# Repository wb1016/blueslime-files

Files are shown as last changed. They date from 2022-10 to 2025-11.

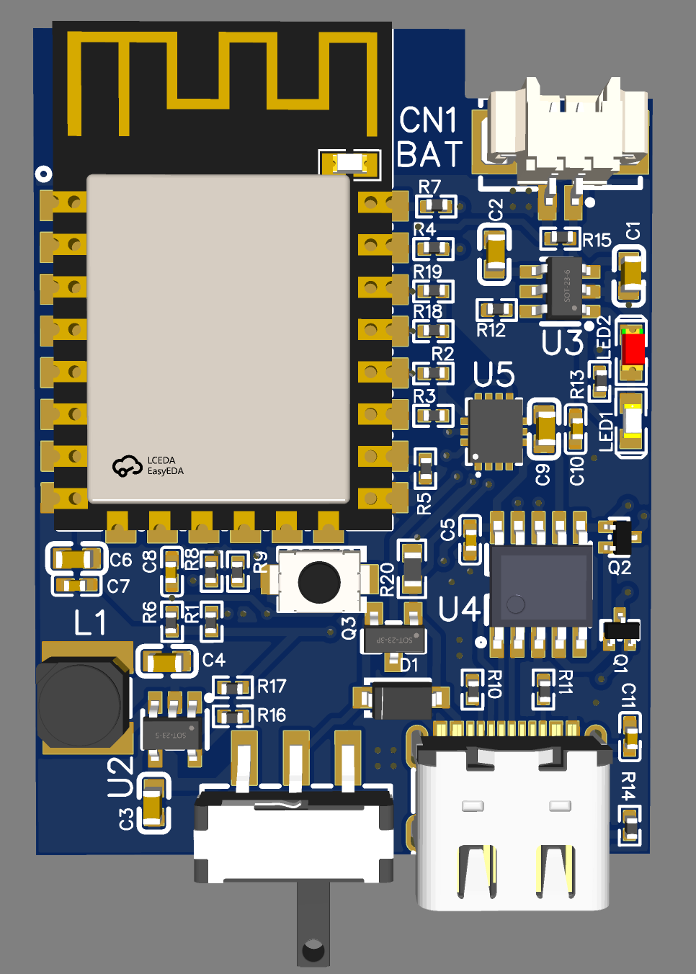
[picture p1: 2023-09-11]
r5-0904/3dpreview.png

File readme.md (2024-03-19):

# DISCONTINUED
see [BlueSlime-C3](https://github.com/wb1016/BlueSlime-C3) instead
# BlueSlime SlimeVR PCB Assembly
SlimeVR tracker hardware based on Wemos D1 Mini. comes with various revision.
### what revision should i select?
| revision | IMU | test | case | AUX |
|---|-----|---|---|-----|
| R1 | BMI160 | fail | y | y |
| R2 | BMI160 | untested | y | y | 
| R3 | BMI160 | untested | n | y |
| R3 (modular) | BMI160 | untested | n | y |
| R4 | BMI160 | untested | y | y |
| R4 (42688) | ICM-42688-P | untested | y | y |
| R5 | BMI270 | tested | y | n |

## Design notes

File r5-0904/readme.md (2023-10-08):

# revision 5 - 2023 09 04
first implementation of buck convertor and BMI270. better tracking performance and better power efficiency. extension is omitted.
## specs
- BMI270 IMU
- TP4057 500mA
- battery charge switch MOSFET
- reset button
- 51021 RB type battery connector
- optional JST-PH battery connector
- no THT components 
- 3x4cm form-factor
- flat bottom surface
## firmware configuration
- Board: WeMos D1 Mini
- Primary IMU: BMI270
- IMU Rotation: 0
- battery detection 180k ohm (default)
## battery requirements
DTP103040 will work flawlessly
- 51021 connector or JST-PH 2 pin connector
- integrated over-discharge protection circuit
- 10x30x40mm size

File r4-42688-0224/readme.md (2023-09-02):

# rev 4 (ICM-42688) - 2023 02 24
same with revision 4 but comes with ICM-42688-P IMU. maybe this is the most dense SlimeVR tracker i think. external oscilator clock enabled.

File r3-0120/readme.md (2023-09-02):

# revision 3 - 2023 01 20
similar with R2, but omitted some components and used experimental form factor.
## specs
- BMI160 IMU
- TC4056A 500mA
- FS312F-G battery protection IC
- battery protection MOSFET
- 51021 RB type battery connector
- optional JST-PH battery connector
- JST-PH extension connector
## firmware configuration
- Board: WeMos D1 Mini
- Primary IMU: BMI160
- IMU Rotation: 90 or 270
- battery detection 180k ohm (default)

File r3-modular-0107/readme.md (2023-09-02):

# revision 3 (modular version) - 2023 01 07
same with R3 but uses IMU module instead of doing SMT.

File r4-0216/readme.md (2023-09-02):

# revision 4 - 2023 02 16
huge revolution in form-factor. it comes with small size of 3x4cm. battery protection circuit is omitted since protected battery comes with them.
## specs
- BMI160 IMU
- TP4057 500mA
- battery charge switch MOSFET
- reset button
- 51021 RB type battery connector
- optional JST-PH battery connector
- JST-GH extension connector
- no THT components 
- 3x4cm form-factor
- flat bottom surface
## firmware configuration
- Board: WeMos D1 Mini
- Primary IMU: BMI160
- IMU Rotation: 90 or 270
- battery detection 180k ohm (default)
## battery requirements
DTP103040 will work flawlessly
- 51021 connector or JST-PH 2 pin connector
- integrated over-discharge protection circuit
- 10x30x40mm or 8x40x40 size

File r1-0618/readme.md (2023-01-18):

# revision 1 - 2022 06 18 
this is experimental early prototype. though this revision can operate without major issue, it designed under bad engineering practice. im not releasing PCB schematic.

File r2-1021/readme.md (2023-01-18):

# revision 2 - 2022 10 21
it is first revision that does not require additional fixes. and it is DIY-ready. you can order the assembled PCB with minimal modification.
## specs
- TP4056 500mA
- FS312F-G battery protection IC
- battery protection MOSFET
- reset button
- 51021 RB type battery connector
- optional JST-PH battery connector
- JST-GH extension connector
- no THT components

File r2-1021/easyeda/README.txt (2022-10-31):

<p>asdf</p>            
How to use：

At editor, open the document via: Top menu - File - Open - EasyEDA... , and select the json file, then open it at the editor, you can save it into a project.

如何使用：

打开编辑器，通过：顶部菜单 - 文件 - 打开 - 立创EDA... ，选择 json 文件打开在编辑器，你可以保存文档进工程里面。

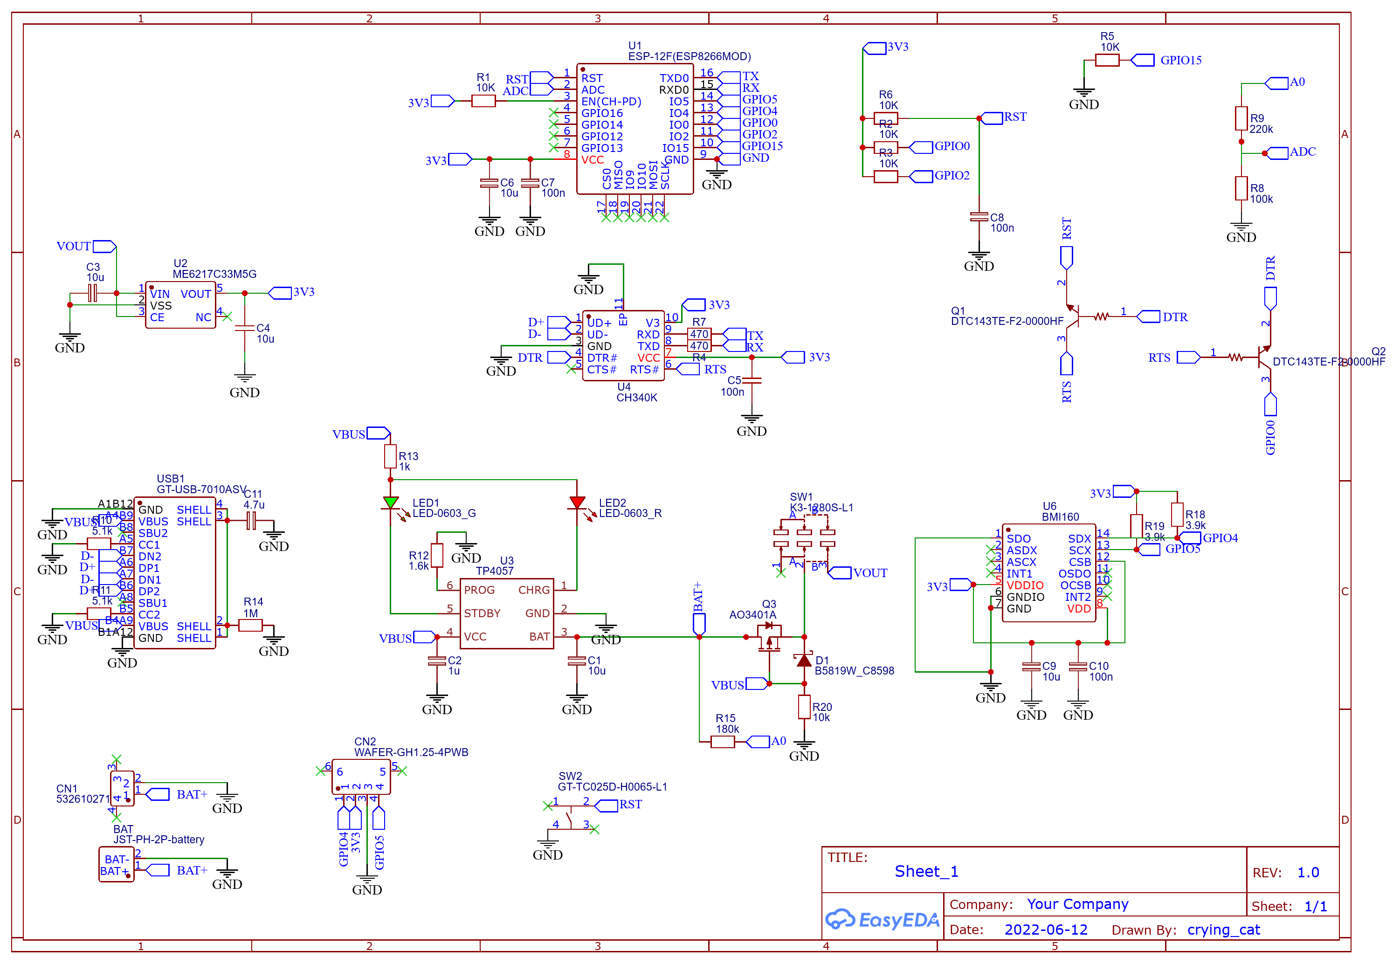
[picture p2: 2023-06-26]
r4-0216/Schematic.png

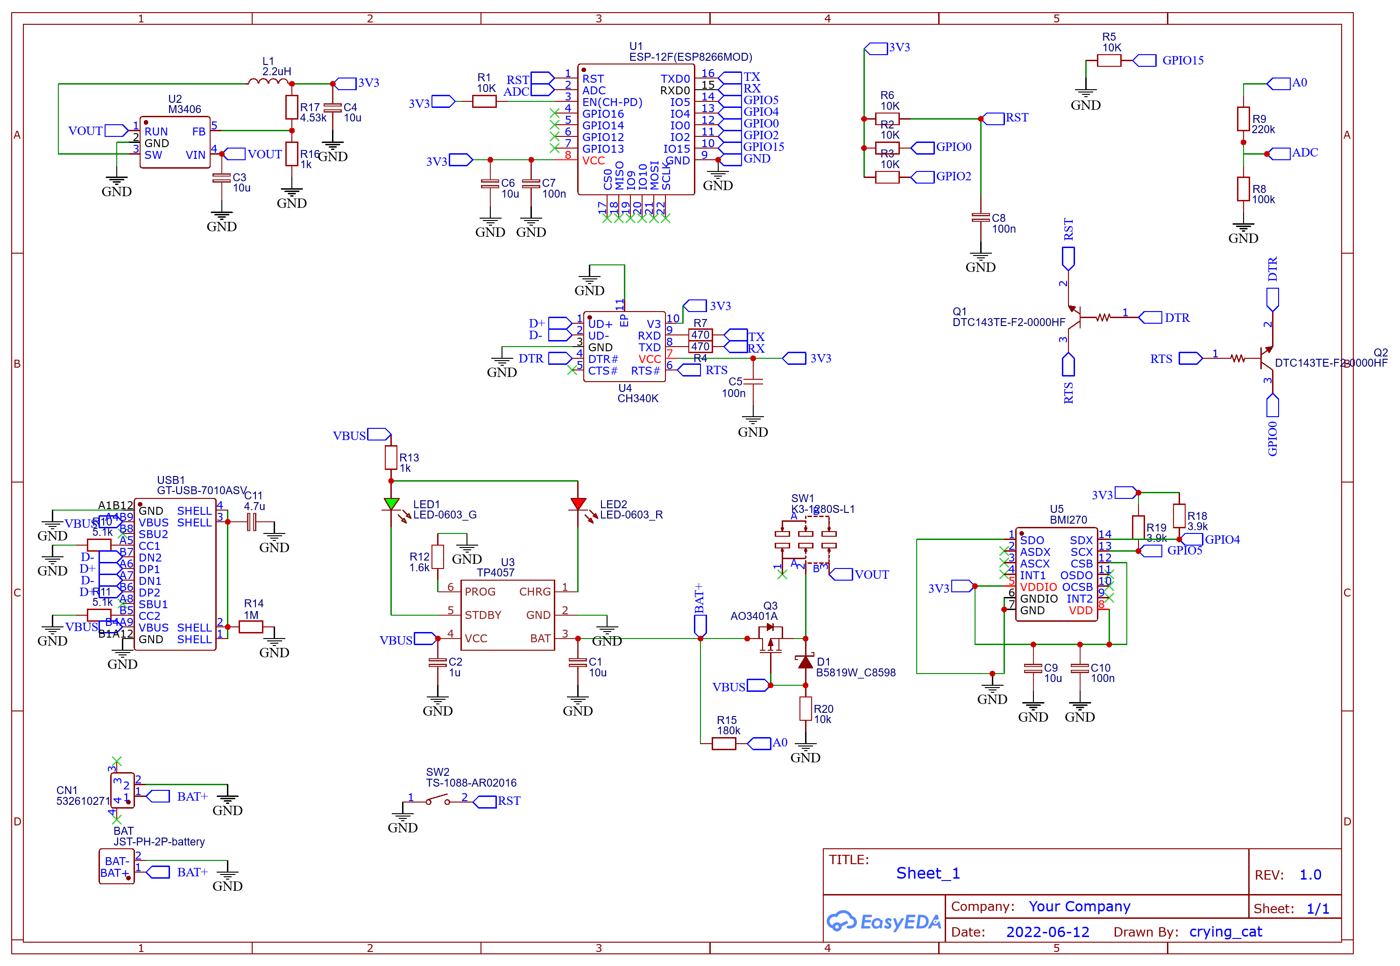
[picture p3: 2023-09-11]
r5-0904/Schematic.png

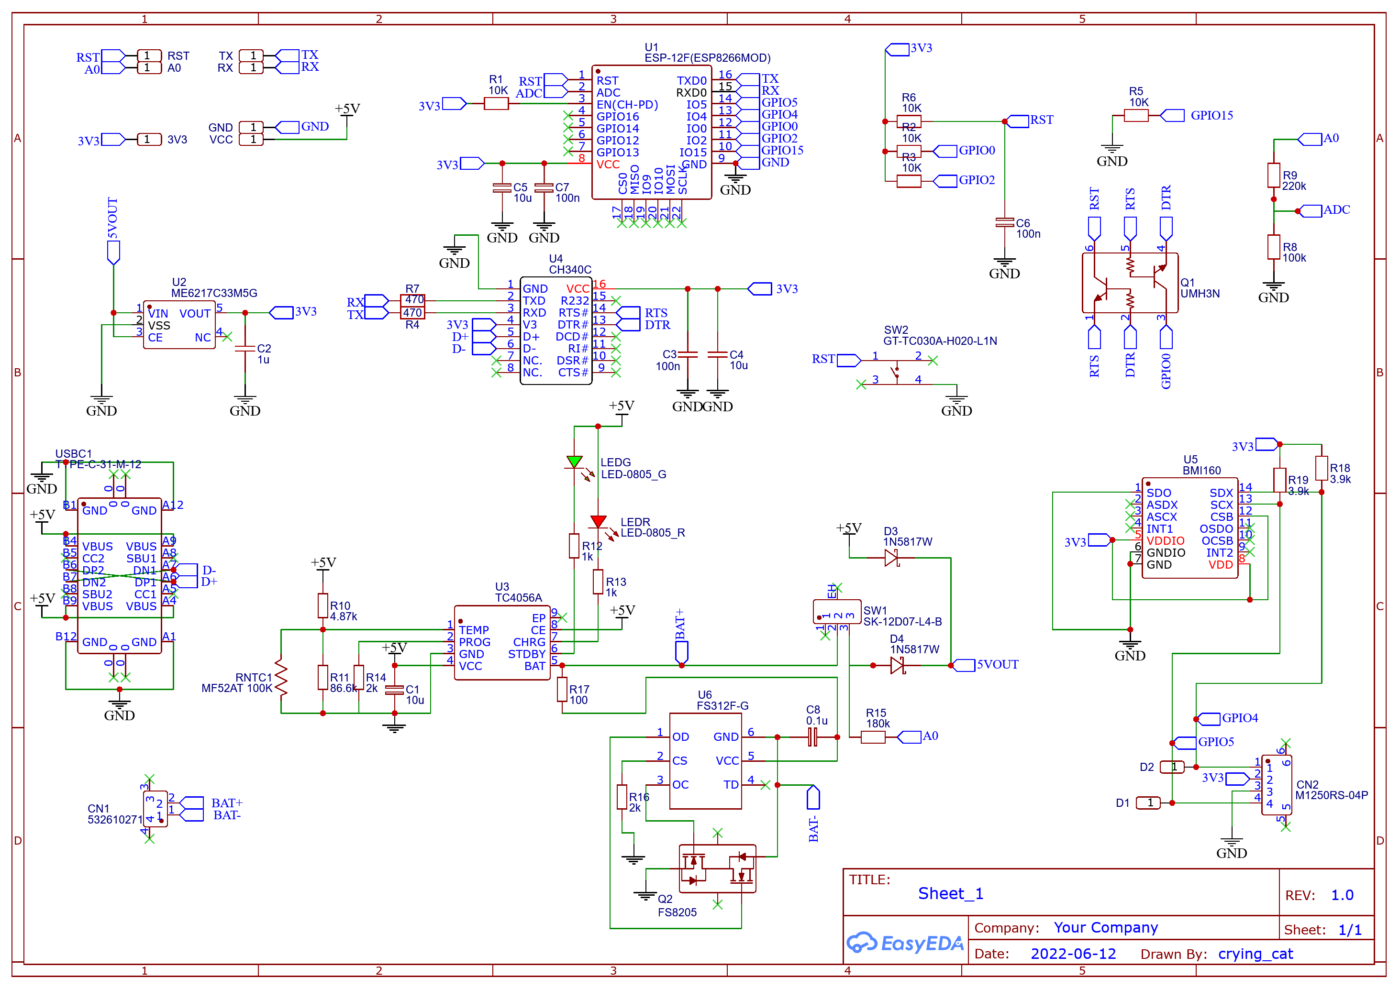
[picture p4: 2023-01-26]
r1-0618/Schematic_SLIMEBOARD-0618_2023-01-26.png

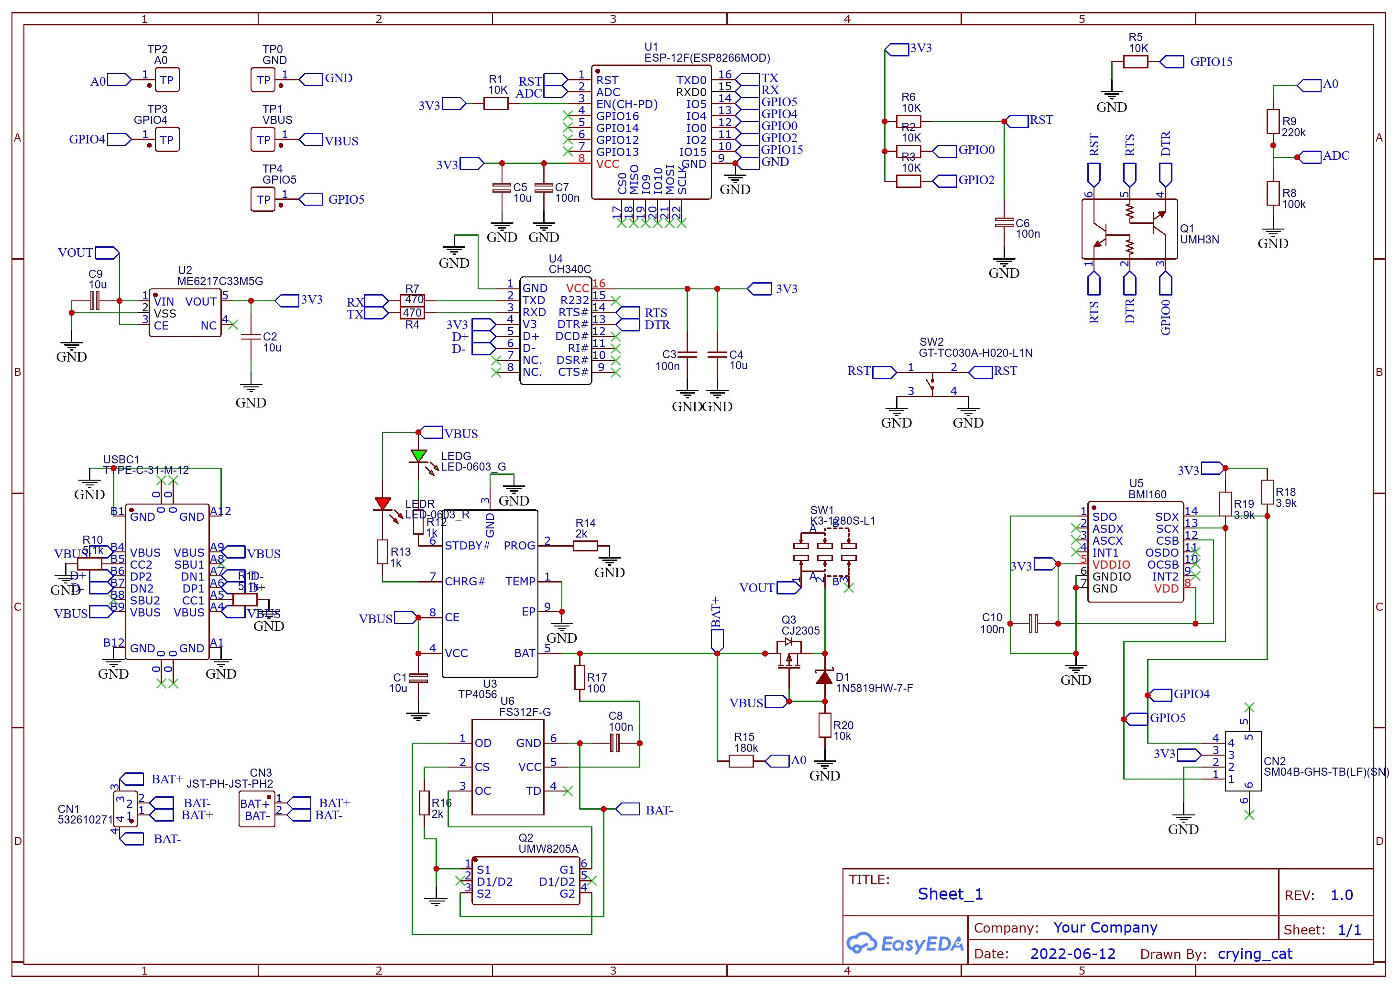
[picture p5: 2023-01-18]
r2-1021/Schematic.png

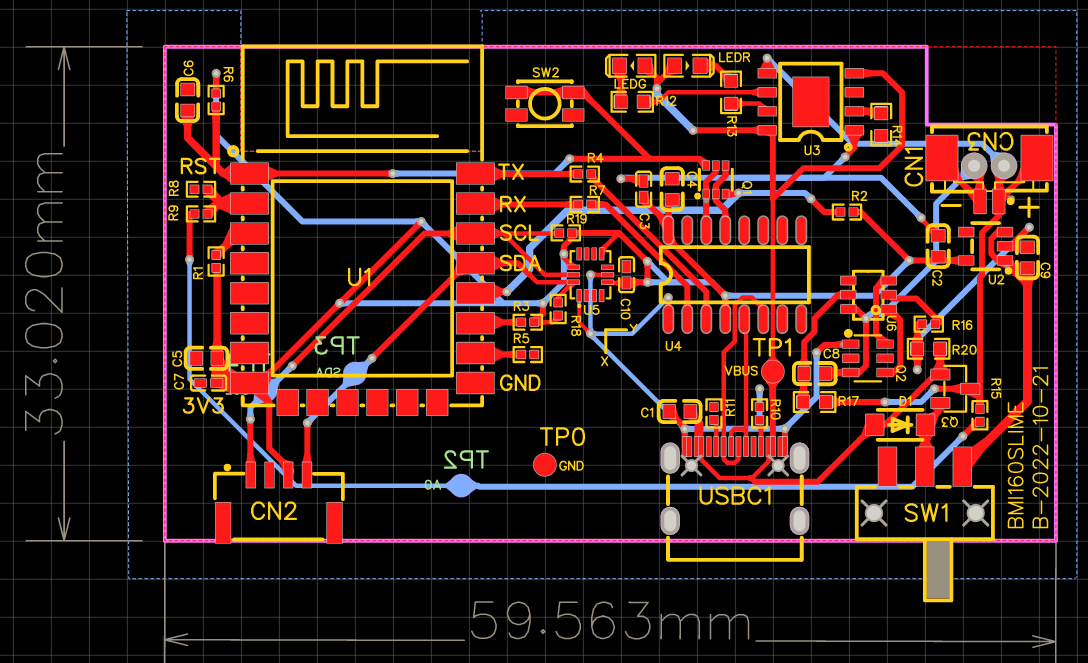
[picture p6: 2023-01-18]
r2-1021/pcbpreview.png

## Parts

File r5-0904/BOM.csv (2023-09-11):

ID | Name | Designator | Footprint | Quantity | Manufacturer Part | Manufacturer | Supplier | Supplier Part | Price
1 | 10u | C3,C4,C1,C6,C9 | C0603 | 5
2 | 2.2uH | L1 | IND-SMD_L4.0-W4.0_SLS3D16S2R2NTT | 1 | SLS3D16S2R2NTT | Sunltech(韩国顺磁) | LCSC | C364100 | 0.13
3 | 1k | R16,R13 | R0402 | 2
4 | 4.53k | R17 | R0402 | 1
5 | TS-1088-AR02016 | SW2 | SW-SMD_L3.9-W3.0-P4.45 | 1 | TS-1088-AR02016 | XUNPU(讯普) | LCSC | C720477 | 0.045
6 | M3406 | U2 | SOT-23-5_L3.0-W1.7-P0.95-LS2.8-BR | 1 | M3406-ADJ | 西安航天民芯 | LCSC | C83224 | 0.027
7 | BMI270 | U5 | LGA-14_L3.0-W2.5-P0.50-BR | 1 | BMI270 | Bosch(博世) | LCSC | C2836813 | 1.896
8 | K3-1280S-L1 | SW1 | SW-SMD_K3-1280S-L1 | 1 | K3-1280S-L1 | 韩国韩荣 | LCSC | C223845 | 0.196
9 | 1u | C2 | C0603 | 1
10 | 100n | C5,C7,C8,C10 | C0402 | 4
11 | 4.7u | C11 | C0402 | 1
12 | 532610271 | CN1 | CONN-SMD_532610271 | 1 | 532610271 | MOLEX | LCSC | C189700 | 0.1
13 | B5819W_C8598 | D1 | SOD-123_L2.7-W1.6-LS3.7-RD-1 | 1 | B5819W SL | CJ(江苏长电/长晶) | LCSC | C8598 | 0.029
14 | LED-0603_G | LED1 | LED0603_GREEN | 1 | 19-217/GHC-YR1S2/3T | EVERLIGHT(台湾亿光) | LCSC | C72043 | 0.027
15 | LED-0603_R | LED2 | LED0603_RED | 1 | 19-217/R6C-AL1M2VY/3T | EVERLIGHT(台湾亿光) | LCSC | C72044 | 0.016
16 | DTC143TE-F2-0000HF | Q1,Q2 | SOT-523_L1.6-W0.8-P1.00-LS1.6-BR | 2 | DTC143TE | YANGJIE(扬杰) | LCSC | C968340 | 0.04
17 | AO3401A | Q3 | SOT-23_L2.9-W1.3-P1.90-LS2.4-BR | 1 | AO3401A | AOS | LCSC | C15127 | 0.062
18 | 10K | R1,R2,R3,R5,R6 | R0402 | 5
19 | 470 | R4,R7 | R0402 | 2
20 | 100k | R8 | R0402 | 1
21 | 220k | R9 | R0402 | 1
22 | 180k | R15 | R0402 | 1
23 | 5.1k | R11,R10 | R0402 | 2
24 | 1.6k | R12 | R0402 | 1
25 | 1M | R14 | R0402 | 1
26 | 3.9k | R18,R19 | R0402 | 2
27 | 10k | R20 | R0603 | 1
28 | ESP-12F(ESP8266MOD) | U1 | WIFIM-SMD_ESP-12F-ESP8266MOD | 1 | ESP-12F(ESP8266MOD) | Ai-Thinker | LCSC | C82891 | 2.113
29 | TP4057 | U3 | SOT-23-6_L2.9-W1.6-P0.95-LS2.8-BR | 1 | TP4057-42-SOT26-R | TOPPOWER(南京拓微) | LCSC | C12044 | 0.126
30 | CH340K | U4 | ESOP-10_L4.9-W3.9-P1.00-LS6.2-BL-EP | 1 | CH340K | WCH(南京沁恒) | LCSC | C968586 | 0.681
31 | GT-USB-7010ASV | USB1 | USB-C-SMD_G-SWITCH_GT-USB-7010ASV | 1 | GT-USB-7010ASV | G-Switch(品赞) | LCSC | C2988369 | 0.079

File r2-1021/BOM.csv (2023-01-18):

ID | Name | Designator | Footprint | Quantity | Manufacturer Part | Manufacturer | Supplier | Supplier Part | Price | Pins | 3DModel | Contributor | Package Display | SMT Type | image | license | link
1 | 5.1k | R10,R11 | R0402 | 2 |  |  |  |  |  | 2 | R0402_L1.0-W0.5-H0.5 | LCEDA_Lib |  |  |  |  | https://item.szlcsc.com/323315.html
2 | ESP-12F(ESP8266MOD) | U1 | WIFIM-SMD_ESP-12F-ESP8266MOD | 1 | ESP-12F(ESP8266MOD) | Ai-Thinker | LCSC | C82891 | 0.339 | 22 | WIFIM-SMD_WIFI-L24.0-W16.0-H3.1 | 立创EDA官方封装库 |  |  |  |  | https://item.szlcsc.com/84052.html
3 | JST-PH-JST-PH2 | CN3 | JST-PH-JST-PH2 | 1 |  |  |  |  |  | 2 |  | julian.boet
4 | GT-TC030A-H020-L1N | SW2 | SW-SMD_4P-L3.6-W3.0-P1.50-LS4.7 | 1 | GT-TC030A-H020-L1N | G-Switch(品赞) | LCSC | C843670 | 0.013 | 4 | SW-SMD_4P-L3.6-W3.0-P1.50-LS4.7 | LCSC |  |  |  |  | https://item.szlcsc.com/902756.html
5 | TP4056 | U3 | ESOP-8_L4.9-W3.9-P1.27-LS6.0-BL-EP | 1 | TP4056 | TOPPOWER | LCSC | C16581 | 0.03 | 9 | ESOP-8_L4.9-W3.9-H1.6-LS6.0-P1.27 | Guest |  |  |  |  | https://www.mornsun.cn/html/pdf/SCM1501B.html
6 | 470 | R4,R7 | R0402 | 2 |  |  |  |  |  | 2 | R0402_L1.0-W0.5-H0.5 | LCEDA_Lib |  |  |  |  | https://item.szlcsc.com/323315.html
7 | K3-1280S-L1 | SW1 | SW-SMD_K3-1280S-L1 | 1 | K3-1280S-L1 | Rectangular Connectors - Contacts | LCSC | C223845 | 0.031 | 3 | SW-SMD_K3-1280S-L1 | LCSC | No |  |  |  | https://item.szlcsc.com/223990.html
8 | SM04B-GHS-TB(LF)(SN) | CN2 | CONN-SMD_4P-P1.25_SM04B-GHS-TB-LF-SN | 1 | SM04B-GHS-TB(LF)(SN) | JST Sales America | LCSC | C189895 | 0.027 | 6 | CONN-SMD_GH1.25-WS-4P | LCSC |  |  |  |  | https://lcsc.com/product-detail/Wire-To-Board-Wire-To-Wire-Connector_JST-Sales-America_SM04B-GHS-TB-LF-SN_JST-Sales-America-SM04B-GHS-TB-LF-SN_C189895.html
9 | 100k | R8 | R0402 | 1 |  |  |  |  |  | 2 | R0402_L1.0-W0.5-H0.5 | LCEDA_Lib |  |  |  |  | https://item.szlcsc.com/323315.html
10 | LED-0603_G | LEDG | LED0603_GREEN | 1 | 19-217/GHC-YR1S2/3T | EVERLIGHT(台湾亿光) | LCSC | C72043 | 0.004 | 2 | LED0603-RD_GREEN | LCEDA_Lib
11 | LED-0603_R | LEDR | LED0603_RED | 1 | 19-217/R6C-AL1M2VY/3T | EVERLIGHT(台湾亿光) | LCSC | C72044 | 0.003 | 2 | LED0603_Red | LCEDA_01
12 | 100n | C3,C7,C10 | C0402 | 3 |  |  |  |  |  | 2 | C0402_L1.0-W0.5-H0.5 | LCEDA_Lib |  |  |  |  | https://item.szlcsc.com/15869.html
13 | 100n | C8 | C0603 | 1 | ? |  |  |  |  | 2 | C0603_L1.6-W0.8-H0.8 | lcsc |  |  |  |  | https://item.szlcsc.com/362304.html
14 | 10K | R1,R2,R3,R5,R6 | R0402 | 5 |  |  |  |  |  | 2 | R0402_L1.0-W0.5-H0.5 | LCEDA_Lib |  |  |  |  | https://item.szlcsc.com/323315.html
15 | 220k | R9 | R0402 | 1 |  |  |  |  |  | 2 | R0402_L1.0-W0.5-H0.5 | LCEDA_Lib |  |  |  |  | https://item.szlcsc.com/323315.html
16 | 180k | R15 | R0402 | 1 |  |  |  |  |  | 2 | R0402_L1.0-W0.5-H0.5 | LCEDA_Lib |  |  |  |  | https://item.szlcsc.com/323315.html
17 | 2k | R16 | R0402 | 1 | ? |  |  |  |  | 2 | R0402_L1.0-W0.5-H0.5 | lcsc |  |  |  |  | https://item.szlcsc.com/323315.html
18 | 3.9k | R18,R19 | R0402 | 2 |  |  |  |  |  | 2 | R0402_L1.0-W0.5-H0.5 | LCEDA_Lib |  |  |  |  | https://item.szlcsc.com/323315.html
19 | UMW8205A | Q2 | SOT-23-6_L2.9-W1.6-P0.95-LS2.8-BL | 1 | UMW8205A | Youtai Semiconductor Co., Ltd. | LCSC | C351449 | 0.008 | 6 | SOT-23-6_L2.9-W1.6-H1.5-LS2.8-P0.95 | LCSC |  |  |  |  | https://item.szlcsc.com/169042.html
20 | 1N5819HW-7-F | D1 | SOD-123_L2.8-W1.8-LS3.7-FD | 1 | 1N5819HW-7-F | DIODES | LCSC | C82544 | 0.006 | 2 | SOD-123_L2.8-W1.8-H1.4-LS3.7 | lcsc |  |  |  |  | https://item.szlcsc.com/182946.html
21 | CJ2305 | Q3 | SOT-23-3_L2.9-W1.3-P1.90-LS2.4-BR | 1 | CJ2305 | CJ | LCSC | C8549 | 0.008 | 3 | SOT-23-3P_L2.9-W1.3-H1.0-LS2.4-P0.95 | 立创EDA官方封装库 |  |  |  |  | https://www.diodes.com/assets/Package-Files/SOT23.pdf
22 | 10k | R20 | R0603 | 1 |  |  |  |  |  | 2 | R0603_L1.6-W0.8-H0.8 | LCEDA_Lib |  |  |  |  | https://www.mouser.in/datasheet/2/447/PYu_RT_1_to_0_01_RoHS_L_11-1669912.pdf
23 | 10u | C2,C4,C5,C9 | C0603 | 4 |  |  |  |  |  | 2 | C0603_L1.6-W0.8-H0.8 | LCEDA_Lib |  |  |  |  | https://item.szlcsc.com/362304.html
24 | BMI160 | U5 | LGA-14_L3.0-W2.5-P0.50-BL | 1 | BMI160 | Bosch | LCSC | C94021 | 0.431 | 14 | LGA-14_L2.5-W3.0-H0.9-P0.50 | lcsc |  |  |  |  | https://lcsc.com/product-detail/Sensors_Bosch_BMG250_BMG250_C189521.html
25 | 10u | C1 | C0603 | 1 | ? |  |  |  |  | 2 | C0603_L1.6-W0.8-H0.8 | lcsc |  |  |  |  | https://item.szlcsc.com/362304.html
26 | 100n | C6 | C0603 | 1 |  |  |  |  |  | 2 | C0603_L1.6-W0.8-H0.8 | LCEDA_Lib |  |  |  |  | https://item.szlcsc.com/362304.html
27 | 532610271 | CN1 | CONN-SMD_532610271 | 1 | 532610271 | MOLEX | LCSC | C189700 | 0.018 | 4 | CONN-SMD_532610271 | LCSC |  |  |  |  | https://item.szlcsc.com/202929.html
28 | UMH3N | Q1 | SC-70-6_L2.2-W1.3-P0.65-LS2.1-BR | 1 | UMH3N | CJ | LCSC | C62892 | 0.009 | 6 | SC-70-6_L2.1-W1.3-H1.0-LS2.1-P0.65 | lcsc |  | Extend | //image.lceda.cn/szlcsc/C62892.jpg |  | https://item.szlcsc.com/112963.html
29 | FS312F-G | U6 | SOT-23-6 | 1 | DW01+G | FORTUNE | LCSC | C14213 | 0.023 | 6 | SOT-23-6_L2.8-W1.6-H1.3-LS2.8-P0.95 | KiCAD |  |  |  | https://www.gnu.org/licenses/lgpl-2.1.html
30 | 1k | R12,R13 | R0603 | 2 | ? |  |  |  |  | 2 | R0603_L1.6-W0.8-H0.8 | lcsc |  |  |  |  | https://www.mouser.in/datasheet/2/447/PYu_RT_1_to_0_01_RoHS_L_11-1669912.pdf
31 | 2k | R14 | R0603 | 1 | ? |  |  |  |  | 2 | R0603_L1.6-W0.8-H0.8 | lcsc |  |  |  |  | https://www.mouser.in/datasheet/2/447/PYu_RT_1_to_0_01_RoHS_L_11-1669912.pdf
32 | 100 | R17 | R0603 | 1 | ? |  |  |  |  | 2 | R0603_L1.6-W0.8-H0.8 | lcsc |  |  |  |  | https://www.mouser.in/datasheet/2/447/PYu_RT_1_to_0_01_RoHS_L_11-1669912.pdf
33 | ME6217C33M5G | U2 | SOT-23-5_L3.0-W1.7-P0.95-LS2.8-BR | 1 | ME6217C33M5G | Nanjing Micro One Elec | LCSC | C427602 | 0.014 | 5 | SOT-23-5_L2.9-W1.6-H1.1-LS2.8-P0.95 | LCSC |  |  |  |  | https://item.szlcsc.com/236104.html
34 | CH340C | U4 | SOP-16_L10.0-W3.9-P1.27-LS6.0-BL | 1 | CH340C | WCH | LCSC | C84681 | 0.076 | 16 | SOP-16_L9.9-W3.9-H1.5-LS6.0-P1.27 | marphxl |  | Extend |  |  | https://item.szlcsc.com/391677.html
35 | TYPE-C-31-M-12 | USBC1 | USB-C_SMD-TYPE-C-31-M-12 | 1 | TYPE-C-31-M-12 | Rectangular Connectors - Contacts | LCSC | C165948 | 0.036 | 20 | USB-C_SMD-TYPE-C-31-M-12 | LCSC |  |  |  |  | https://so.szlcsc.com/global.html?c=&k=C165948

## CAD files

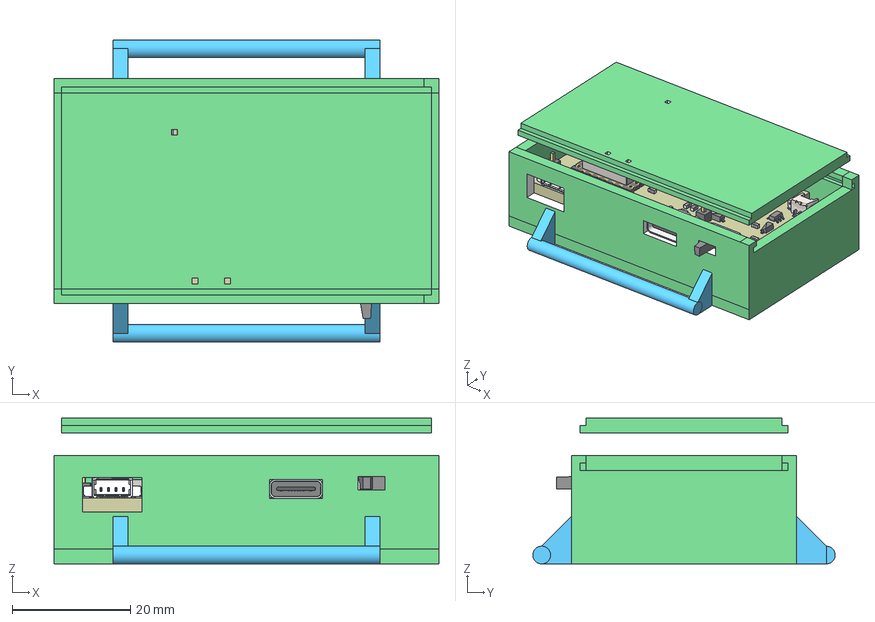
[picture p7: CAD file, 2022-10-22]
r1-0618/ASSEMBLY_SLIMEBOARD-0618-4.3mf
65.0 x 51.1 x 24.6 mm

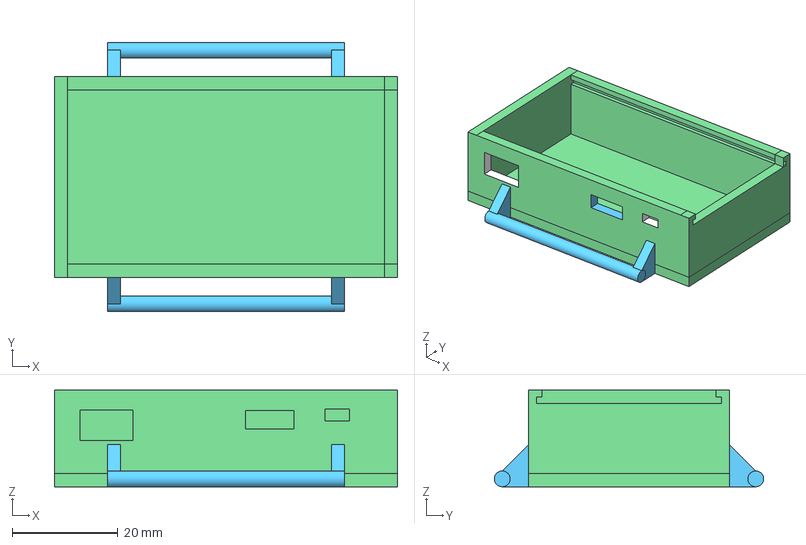
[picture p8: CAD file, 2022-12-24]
r1-0618/CASE-BOTTOM_SLIMEBOARD-0618.3mf
65.0 x 51.1 x 18.3 mm

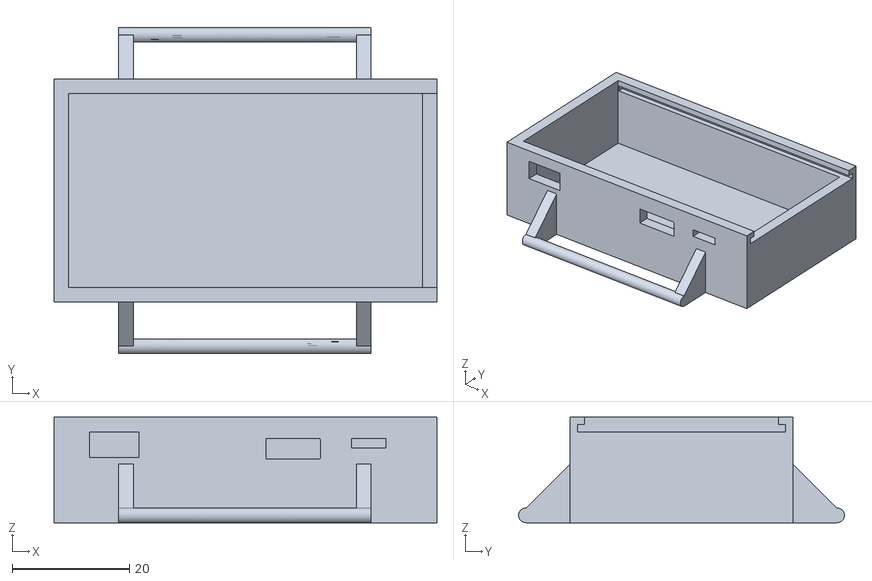
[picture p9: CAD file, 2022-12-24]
r2-1021/case.stl
65.2 x 55.5 x 18.0

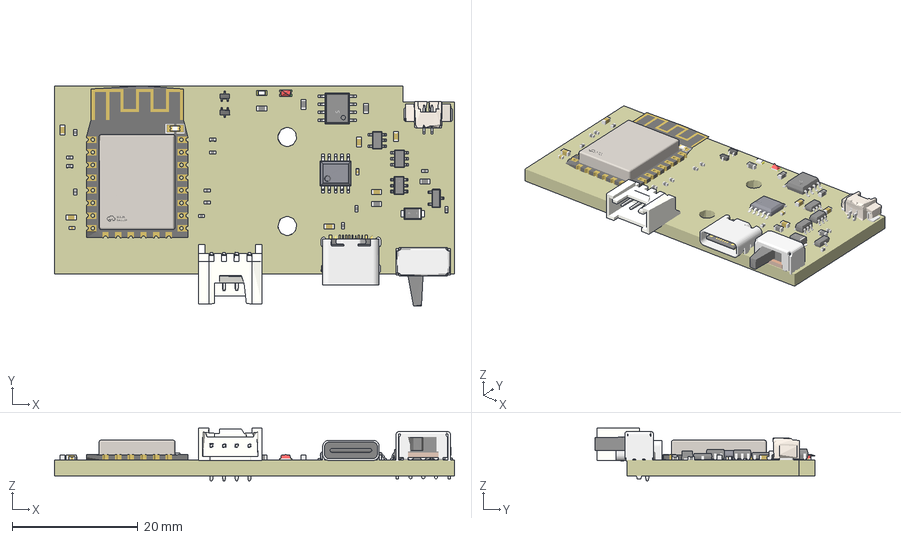
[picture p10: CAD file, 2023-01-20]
r3-modular-0107/OBJ_PCB.3mf
63.5 x 35.0 x 8.34 mm

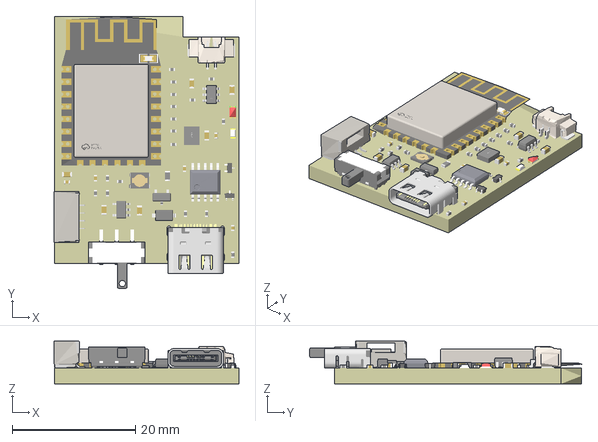
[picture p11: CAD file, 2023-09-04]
r4-0216/PCB.3mf
30.0 x 44.1 x 6.94 mm

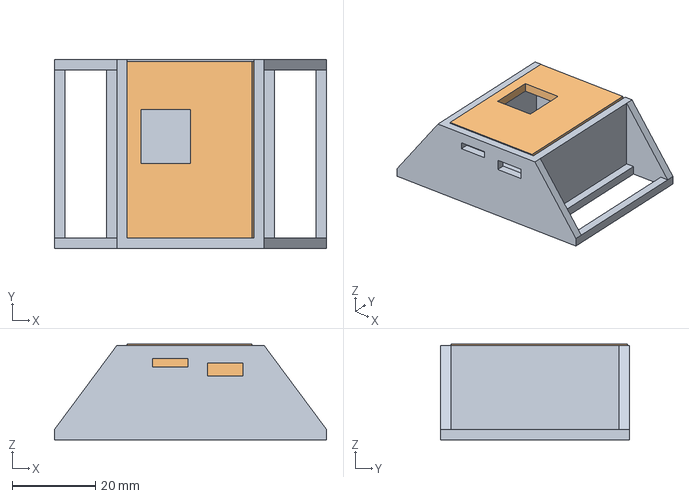
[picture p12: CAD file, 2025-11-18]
r5-0904/case.FCStd
65.5 x 45.5 x 23.0 mm
top

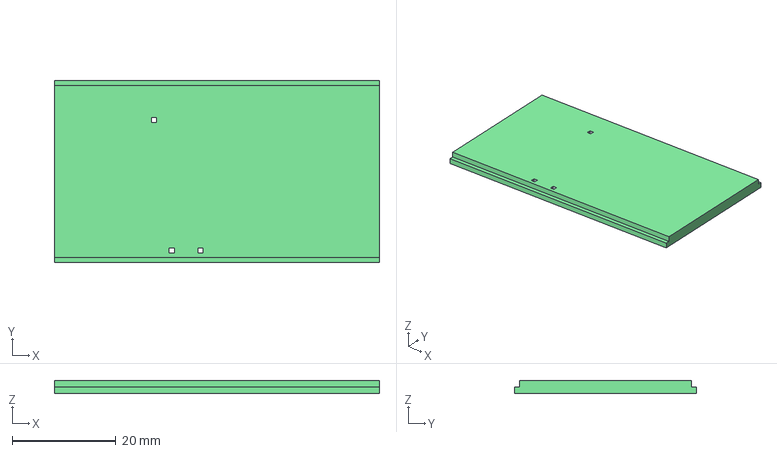
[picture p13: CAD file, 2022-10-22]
r1-0618/CASE-TOP_SLIMEBOARD-0618.3mf
62.5 x 35.0 x 2.50 mm

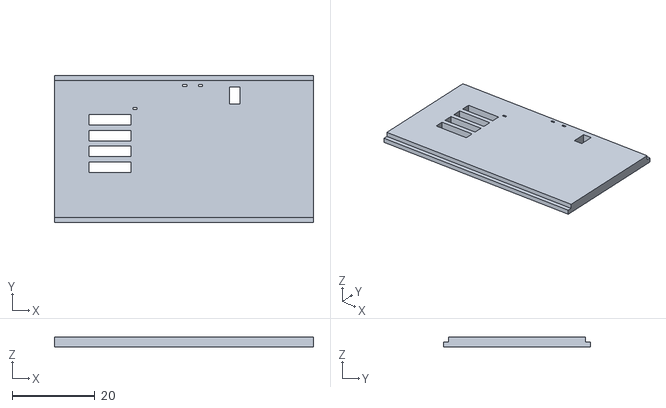
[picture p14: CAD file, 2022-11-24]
r2-1021/lid.stl
62.5 x 35.5 x 2.50

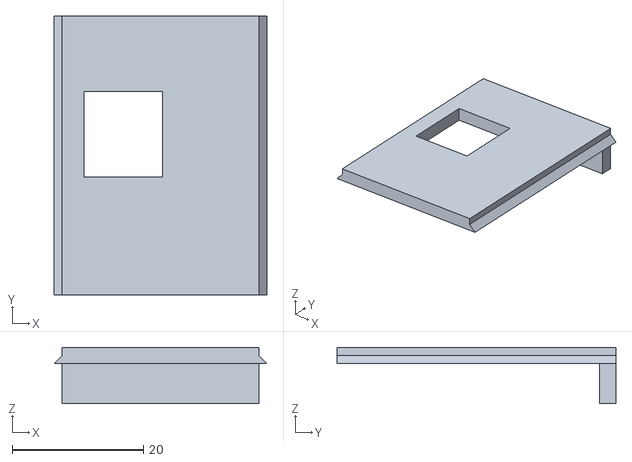
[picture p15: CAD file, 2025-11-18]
r5-0904/case-top.stl
32.5 x 42.5 x 8.60

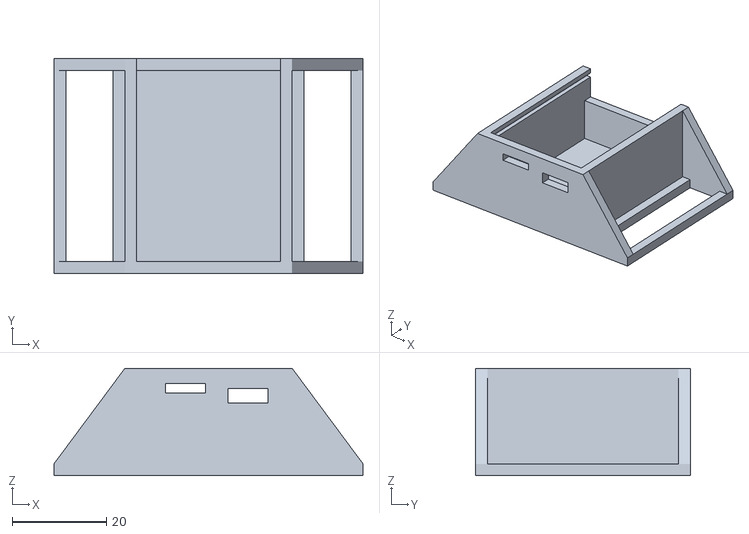
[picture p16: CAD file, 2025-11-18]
r5-0904/case-body.stl
65.5 x 45.5 x 22.7

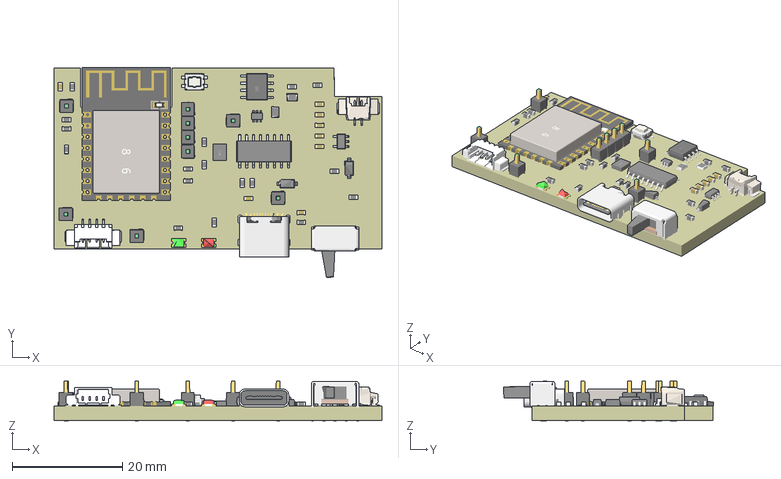
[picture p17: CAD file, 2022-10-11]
r1-0618/OBJ_PCB_SLIMEBOARD-0618.3mf
59.6 x 38.1 x 7.23 mm

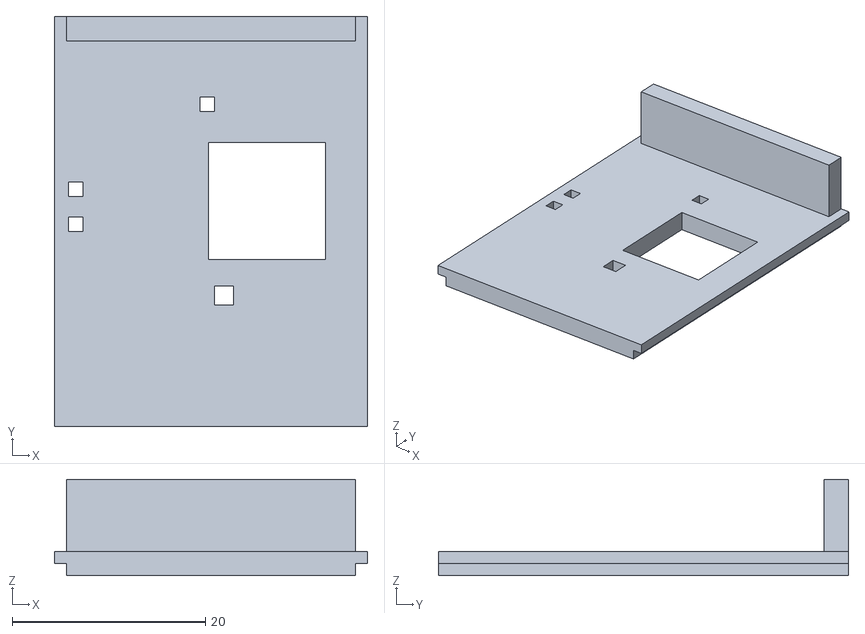
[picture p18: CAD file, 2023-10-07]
r5-0904/lid-103040.stl
32.5 x 42.5 x 9.99

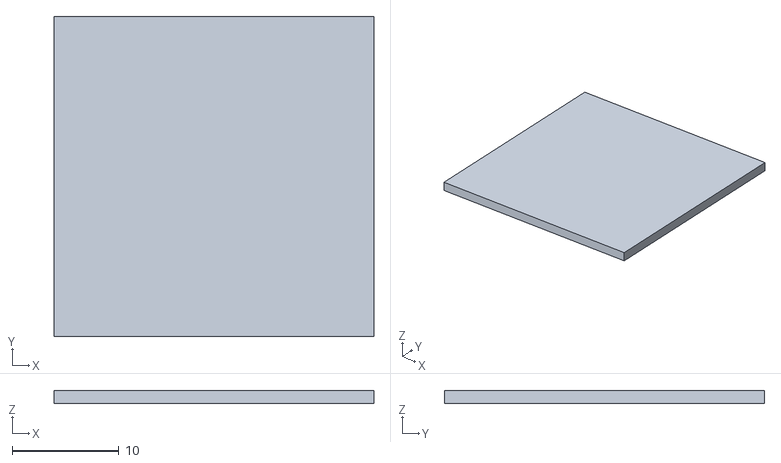
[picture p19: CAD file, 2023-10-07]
r5-0904/spacer.stl
30.0 x 30.0 x 1.24

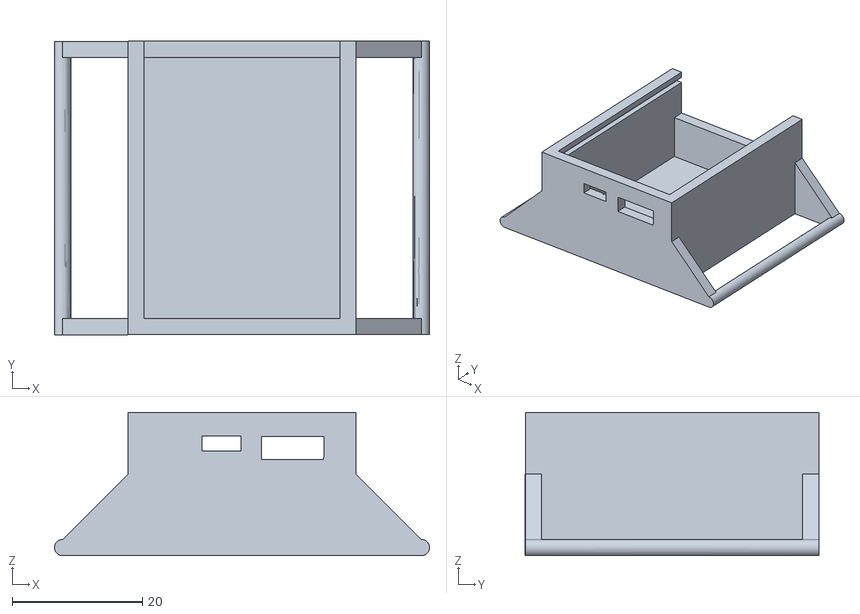
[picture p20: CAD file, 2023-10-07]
r5-0904/case-103040.stl
57.5 x 45.0 x 22.0

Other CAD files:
r5-0904/OBJ_PCB-r5.3mf
r4-0216/103040-case-main.stl
r4-0216/804040-lid.stl
r4-0216/103040-case-lid.stl
r1-0618/CASE-BOTTOM_SLIMEBOARD-0618.stl
r1-0618/CASE-TOP_SLIMEBOARD-0618.stl
r4-0216/804040-case.stl
r4-0216/804040-tray.stl

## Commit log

2022-10-11 3D models of case and PCB
    [ASSEMBLY_SLIMEBOARD-0618-4.3mf, CASE-BOTTOM_SLIMEBOARD-0618.3mf, CASE-BOTTOM_SLIMEBOARD-0618.stl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]
2022-10-12 fix strap mount size
    [ASSEMBLY_SLIMEBOARD-0618-4.3mf, CASE-BOTTOM_SLIMEBOARD-0618.3mf, CASE-BOTTOM_SLIMEBOARD-0618.stl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]
2022-10-22 wall thickness 2.5mm
    [ASSEMBLY_SLIMEBOARD-0618-4.3mf, CASE-BOTTOM_SLIMEBOARD-0618.3mf, CASE-BOTTOM_SLIMEBOARD-0618.stl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]
2022-11-24 add JST-PH connector as option to battery connector
2022-11-24 add 1021 stl
    [case_bmislime-1021.stl, lid_bmislime-1021.stl]
2022-12-24 enlarge usb connector hole
    [CASE-BOTTOM_SLIMEBOARD-0618.3mf, CASE-BOTTOM_SLIMEBOARD-0618.stl, case_bmislime-1021.stl]
2023-01-09 change battery connector type to 51021 RB
2023-01-31 replace MOSFET and SBD as JLC basic parts, DRC error fix
2023-03-06 add case files
    [PCB.3mf, case-lid.stl, case-main.stl]
2023-05-01 fix DRC errors, JST-PH battery connector add
    [103040-case-lid.stl, 103040-case-main.stl]
2023-05-01 support 804040 battery
    [804040-case.stl, 804040-lid.stl, 804040-tray.stl]
2023-06-26 add reset switch
    [103040-case-lid.stl, 804040-lid.stl, PCB.3mf]
2023-09-02 add more description
    [case.stl, lid.stl]
2023-09-02 add 42688 variant
    [BOM.csv, PickAndPlace.csv]
2023-09-04 0.3mm clearance
    [PCB.3mf, PickAndPlace.csv]
2023-09-11 clearance work, add
    [BOM.csv, OBJ_PCB-r5.3mf, PickAndPlace.csv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]
2023-10-07 update case
    [case-103040.3mf, case-103040.stl, lid-103040.3mf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]
